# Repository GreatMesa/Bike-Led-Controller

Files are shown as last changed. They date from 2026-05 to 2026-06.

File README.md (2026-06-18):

# Bike LED Controller
This project is sponsored by JLCPCB

images

## Introduction
The goal of this project is to add more customizability to bike lights. When I was looking though lights for my bike I found that there was a limited amount of colors and patterns I could use. I wanted to create lights and controllers so I could have a better understanding of what was going on in the controller in terms of current consumption and speed of the bike, things that also were not present in other controllers. In this project, I designed a custom bike ring + a custom led controller board so that I could have a greater level of control.

## Custom LED Ring
For the ring, I decided to split the base and top  of the ring into 8 seperate segments. This was due to the size of the ring being way to big for my bike & in terms of the print time & assembely ease, 8 segments seemed to do the best in those 2 categories. 

For the bottom, in order to connect the segments together, I decided to designed them so they would have a insert slot + a segment that goes into it. For the top, I ended up coating it in a layer of FLEX-SEAL in order to act as a water reppelent + a diffusior once I sanded it down to a degree. Here is one fully assmebled ring in action:

### LED Ring GIF
ezgif-7266f13484eda068

## Custom LED Controller
For the LED contoller, I had multiple goals in mine. The main goal I had was the ability for the contoller to convert a higher voltage input to a stable 5V. To do this, I used the TPS566238RQFR buck converter to convert the input voltage (designed for 2S) into 5V. I also used a AMS1117 to convert the 5V supply into 3.3V for the digital IC's and the ESP32. Speaking of digital IC's, I used 5 in this design, a INA236 to meausre the voltage, current, & power output of the controller, a TMP117 to measure the tempature of the board / enclousre enviroment, a BMI270 to measure the speed of the bike for custom effects, a SN74LVC2T45DCUR to convert the ESP32's 3.3V logic into a usable 5V logic level for the LED, and last but not least the CP2102N to allow communication between the USB pherephial and the ESP32 via UART. Here are the schematics, PCB layouts, & the 3D view.

### Schematic


### PCB Layout


### 3D View


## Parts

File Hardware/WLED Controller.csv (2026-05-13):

Reference | Qty | Value | DNP | Exclude from BOM | Exclude from Board | Footprint | Datasheet
BAT1 | 1 | XT-60 |  |  |  | Connector_AMASS:AMASS_XT60-F_1x02_P7.20mm_Vertical | ~
BZ1 | 1 | Buzzer |  |  |  | Custom-Footprints:CMI97050380SMTTR | ~
C1,C2 | 2 | 22uF |  |  |  | Capacitor_SMD:C_0805_2012Metric | ~
C3 | 1 | 33pF |  |  |  | Capacitor_SMD:C_0402_1005Metric | ~
C4,C5 | 2 | 68uF |  |  |  | Capacitor_SMD:CP_Elec_6.3x5.8 | ~
C6,C7 | 2 | 10uF |  |  |  | Capacitor_SMD:C_0805_2012Metric | ~
C8 | 1 | 4.7uF |  |  |  | Capacitor_SMD:C_0603_1608Metric | ~
C9,C10,C11,C12,C13,C14,C15,C16 | 8 | 100nF |  |  |  | Capacitor_SMD:C_0402_1005Metric | ~
C17 | 1 | 4.7uf |  |  |  | Capacitor_SMD:C_0603_1608Metric | ~
D1 | 1 | LED |  |  |  | LED_SMD:LED_0603_1608Metric | ~
D2 | 1 | TVS |  |  |  | Package_TO_SOT_SMD:SOT-666 | https://www.st.com/resource/en/datasheet/usblc6-2.pdf
H1 | 1 | M1 |  | Excluded from BOM |  | MountingHole:MountingHole_3.2mm_M3_Pad_Via | ~
H2 | 1 | M2 |  | Excluded from BOM |  | MountingHole:MountingHole_3.2mm_M3_Pad_Via | ~
H3 | 1 | M3 |  | Excluded from BOM |  | MountingHole:MountingHole_3.2mm_M3_Pad_Via | ~
H4 | 1 | M4 |  | Excluded from BOM |  | MountingHole:MountingHole_3.2mm_M3_Pad_Via | ~
IC1 | 1 | TPS565242DRLR |  |  |  | Custom-Footprints:SOTFL50P160X60-6N
IC2 | 1 | INA236AIDDFR |  |  |  | Custom-Footprints:SOP65P280X110-8N | https://www.ti.com/lit/ds/symlink/ina232.pdf?ts=1699312390876
IC3 | 1 | TMP117xxDRV |  |  |  | Package_SON:WSON-6-1EP_2x2mm_P0.65mm_EP1x1.6mm | https://www.ti.com/lit/ds/symlink/tmp117.pdf
IC4 | 1 | CP2102N |  |  |  | Package_DFN_QFN:QFN-28-1EP_5x5mm_P0.5mm_EP3.35x3.35mm | https://www.silabs.com/documents/public/data-sheets/cp2102n-datasheet.pdf
IC5 | 1 | SN74LVC2T45DCUR |  |  |  | Package_SO:VSSOP-8_2.3x2mm_P0.5mm | http://www.ti.com/lit/ds/symlink/sn74lvc2t45.pdf
IC6 | 1 | BMI270 |  |  |  | Package_LGA:Bosch_LGA-14_3x2.5mm_P0.5mm | https://www.bosch-sensortec.com/media/boschsensortec/downloads/datasheets/bst-bmi160-ds000.pdf
J1,J2 | 2 | Conn_01x03 |  |  |  | TerminalBlock_Phoenix:TerminalBlock_Phoenix_MKDS-1,5-3_1x03_P5.00mm_Horizontal | ~
J3 | 1 | USB_C_Receptacle_USB2.0_14P |  |  |  | Connector_USB:USB_C_Receptacle_GCT_USB4105-xx-A_16P_TopMnt_Horizontal | https://www.usb.org/sites/default/files/documents/usb_type-c.zip
J4 | 1 | UART |  |  |  | Connector_PinSocket_2.54mm:PinSocket_1x04_P2.54mm_Vertical | ~
L1 | 1 | 2.2uH |  |  |  | Inductor_SMD:L_Coilcraft_XAL5030-XXX | ~
Q1,Q2 | 2 | NPN |  |  |  | Custom-Footprints:SOT95P240X115-3N | https://ngspice.sourceforge.io/docs/ngspice-html-manual/manual.xhtml#cha_BJTs
R1 | 1 | 100k |  |  |  | Resistor_SMD:R_0402_1005Metric | ~
R2 | 1 | 220k |  |  |  | Resistor_SMD:R_0402_1005Metric | ~
R3 | 1 | 33.3k |  |  |  | Resistor_SMD:R_0402_1005Metric | ~
R4 | 1 | 30k |  |  |  | Resistor_SMD:R_0402_1005Metric | ~
R5,R6,R8,R9,R16,R17 | 6 | 4.7k |  |  |  | Resistor_SMD:R_0402_1005Metric | ~
R7 | 1 | 0.01 |  |  |  | Resistor_SMD:R_2512_6332Metric | ~
R10,R13,R14,R15 | 4 | 10k |  |  |  | Resistor_SMD:R_0402_1005Metric | ~
R11,R12 | 2 | 5.1k |  |  |  | Resistor_SMD:R_0402_1005Metric | ~
SW1 | 1 | Enable Switch |  |  |  | Button_Switch_SMD:SW_SPST_TS-1088-xR025 | ~
SW2 | 1 | Boot Switch |  |  |  | Button_Switch_SMD:SW_SPST_TS-1088-xR025 | ~
U1 | 1 | AP1117-33 |  |  |  | Package_TO_SOT_SMD:SOT-223-3_TabPin2 | http://www.diodes.com/datasheets/AP1117.pdf
U2 | 1 | ESP32-WROOM-32E |  |  |  | Custom-Footprints:ESP32-WROOM-32E | https://www.espressif.com/sites/default/files/documentation/esp32-wroom-32e_esp32-wroom-32ue_datasheet_en.pdf

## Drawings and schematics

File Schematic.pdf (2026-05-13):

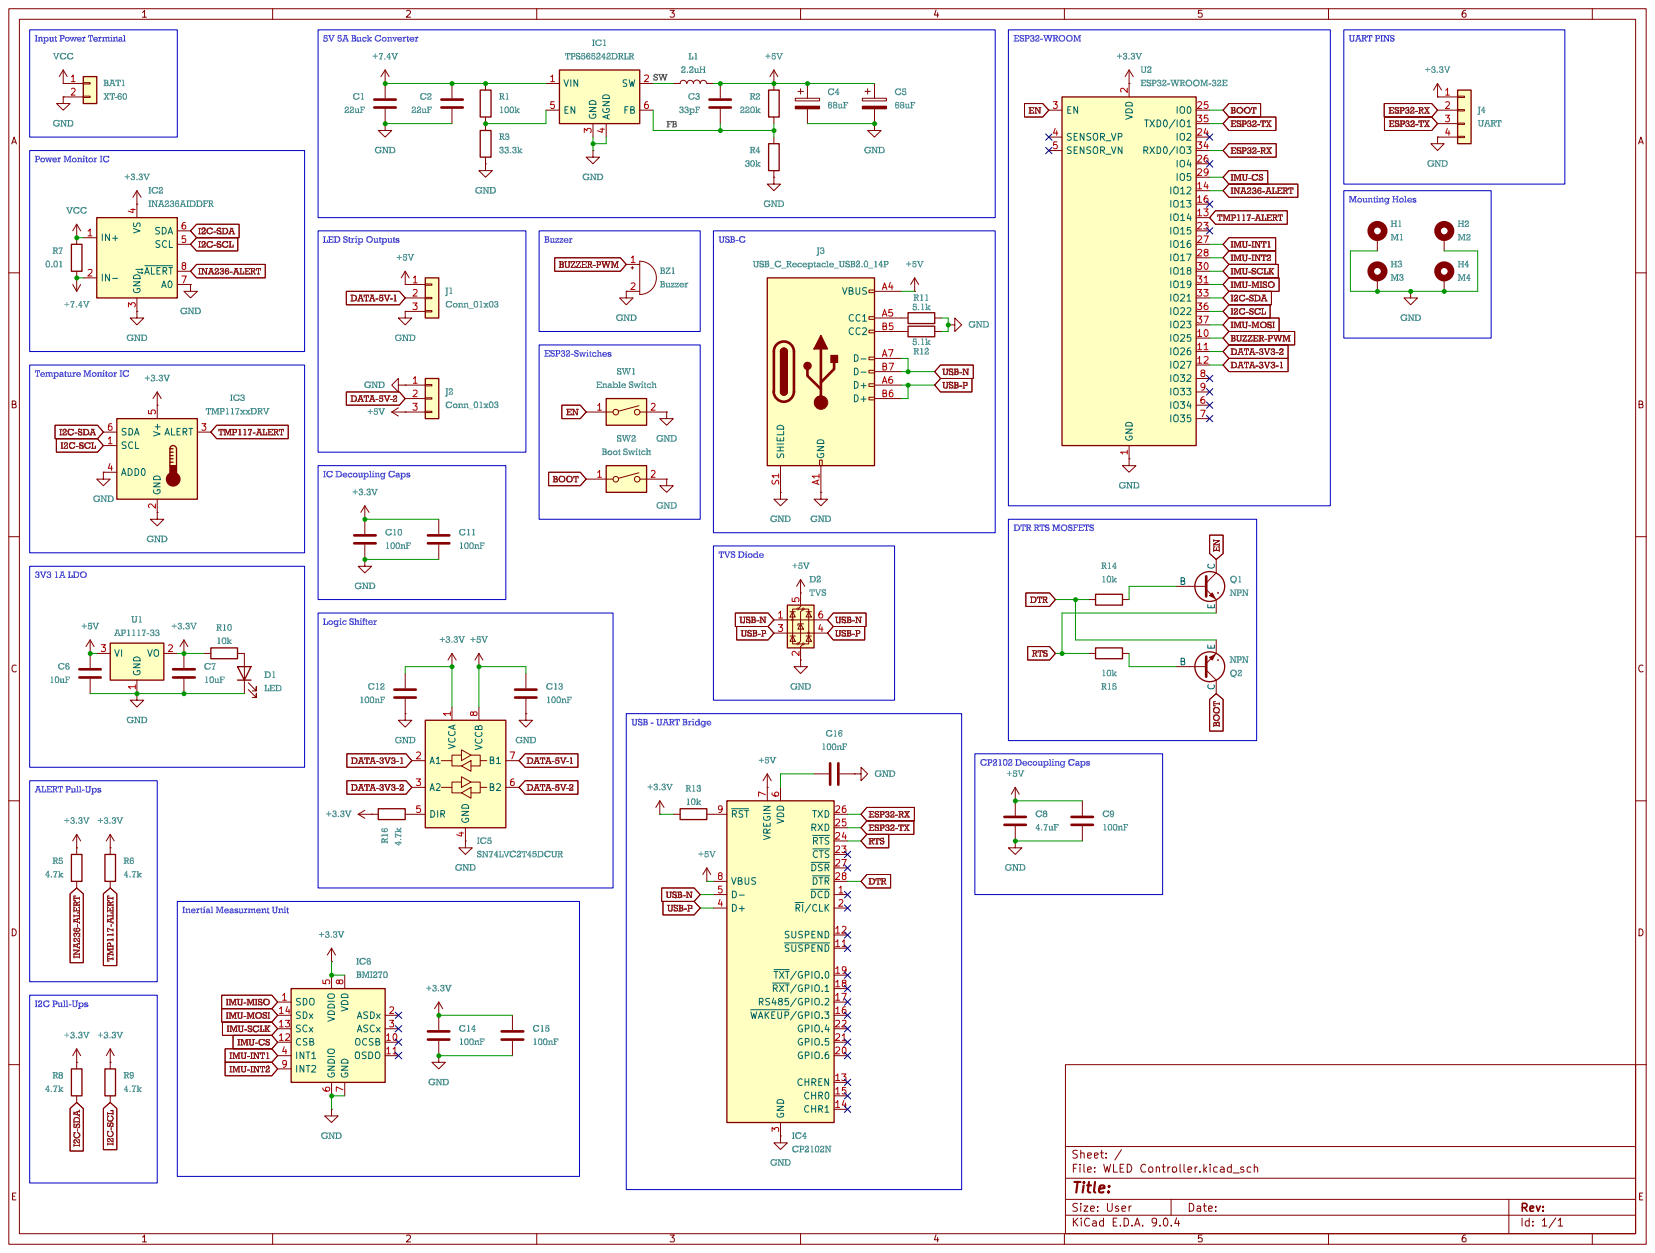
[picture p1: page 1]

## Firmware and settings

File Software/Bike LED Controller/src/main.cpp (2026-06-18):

#include <BLEDevice.h>
#include <BLEUtils.h>
#include <BLEServer.h>
#include <FastLED.h>
#include "patterns.hpp"
#include "ina236.h"
#include "tmp117.h"
#include "bmi270.h"

// How many leds in your strip?
#define NUM_LEDS 300
#define SERVICE_UUID "9648cccb-9798-46d5-8862-cf77ef5b3585"
#define CHARACTERISTIC_UUID "d87a1cc7-8d4d-47c3-a5c3-0c06e6df6fba"

#define DATA_PIN 27

int brightness = 255;
int saturation = 255;
// Define the array of leds
CRGB leds[NUM_LEDS];
ina236 ina;
tmp117 tmp;

SemaphoreHandle_t i2cMutex;
void ina236Task(void *parameters)
{
  for (;;)
  {
    xSemaphoreTake(i2cMutex,portMAX_DELAY);
    ina.updateINA236();
    xSemaphoreGive(i2cMutex);
    vTaskDelay(pdMS_TO_TICKS(50));
  }
}

void tmp117Task(void *parameters)
{
  for (;;)
  {
    xSemaphoreTake(i2cMutex,portMAX_DELAY);
    tmp.getTemperature();
    xSemaphoreGive(i2cMutex);
    vTaskDelay(pdMS_TO_TICKS(100));
  }
}

void ledRender(void * parameters)
{
    for (;;)
  {
    rainbowbreathe(leds, 255,255,20,300);
    vTaskDelay(pdMS_TO_TICKS(100));
  }
}

void setup()
{
  // Uncomment/edit one of the following lines for your leds arrangement.
  // ## Clockless types ##
  FastLED.addLeds<WS2812B, DATA_PIN, GRB>(leds, NUM_LEDS); // GRB ordering is assumed
  Wire.begin();
  Wire.setClock(100000);
  Wire.setTimeOut(10);
  Serial.begin(115200);


  ina.initialize();
  tmp.initialize();

  i2cMutex = xSemaphoreCreateMutex();
  BLEDevice::init("LED Controller");
  BLEServer *pServer = BLEDevice::createServer();
  BLEService *pService = pServer->createService(SERVICE_UUID);
  BLECharacteristic *pCharacteristic = pService->createCharacteristic(
      CHARACTERISTIC_UUID,
      BLECharacteristic::PROPERTY_READ |
          BLECharacteristic::PROPERTY_WRITE);
  pCharacteristic->setValue("Hello World says Neil");
  BLEAdvertising *pAdvertising = pServer->getAdvertising();
  pAdvertising->start();
  pService->start();
  
  xTaskCreatePinnedToCore(ina236Task, "INA236 Task", 4 * 1024, NULL, 1, NULL,1);
  xTaskCreatePinnedToCore(tmp117Task, "TMP117 Task", 4 * 1024, NULL, 1, NULL,1);
  xTaskCreatePinnedToCore(ledRender, "LED Render", 4 * 1024, NULL, 1, NULL,1);
}
CHSV hue1 = CHSV(0, saturation, brightness);
CHSV hue2 = CHSV(200, saturation, brightness);
void loop()
{
  // fadebright(leds, 100, 255, dim8_video(0), dim8_video(200), 10,NUM_LEDS);
  // fadehue(leds,15,160,255,dim8_video(200),10,NUM_LEDS);
  // rainbowfade(leds, saturation, brightness, 15, NUM_LEDS);
  // rainbowbreathe(leds, 255, brightness, 10, NUM_LEDS);
  vTaskDelay(1000);
}

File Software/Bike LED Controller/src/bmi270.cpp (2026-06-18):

#include "bmi270.h"
#include "Arduino.h"

SPISettings settings(1000000, MSBFIRST, SPI_MODE0);

void bmi270::writeRegister(uint8_t reg, uint8_t val)
{
    spi->beginTransaction(settings);
    digitalWrite(5, LOW);
    delayMicroseconds(1);
    spi->transfer(reg & 0x7F);
    spi->transfer(val);
    digitalWrite(5, HIGH);
    spi->endTransaction();
    delayMicroseconds(450); // required idle after write in suspend/low-power mode
}

uint8_t bmi270::readRegister(uint8_t reg)
{
    spi->beginTransaction(settings);
    digitalWrite(5, LOW);
    delayMicroseconds(1);
    spi->transfer(reg | 0x80);
    spi->transfer(0x00); // dummy byte
    uint8_t val = spi->transfer(0x00);
    digitalWrite(5, HIGH);
    spi->endTransaction();
    delayMicroseconds(2); // required 2us idle after read
    return val;
}

bool bmi270::initialize()
{
    spi = &SPI;
    pinMode(5, OUTPUT);
    digitalWrite(5, HIGH);
    pinMode(19, INPUT_PULLDOWN);
    delay(10);

    spi->begin(18, 19, 23, -1);
    delay(10);

    // Dummy read to switch device from I2C mode to SPI mode
    // Result is invalid by design per datasheet section 6.3
    readRegister(0x00);
    delayMicroseconds(200);
    int pass = 0, fail = 0;
    for (int i = 0; i < 100; i++)
    {
        uint8_t id = readRegister(0x00);
        if (id == 0x24)
            pass++;
        else
            fail++;
        delay(10);
    }

    Serial.println(pass);
    Serial.println(fail);

    uint8_t id = readRegister(0x00);
    if (id != 0x24)
        return false;

    return true;
}

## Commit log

2026-05-13 Added all initial files
    [WLED Controller-B_Cu.gbr, WLED Controller-B_Mask.gbr, WLED Controller-B_Paste.gbr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]
2026-06-11 Added current software + hardware
    [Microcontroller.kicad_sch, Power.kicad_sch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]
